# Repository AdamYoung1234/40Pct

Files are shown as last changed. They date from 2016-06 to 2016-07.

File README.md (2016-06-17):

The CW40 (SmallFry 40%) Board
=====

##NOTICE
* This repo is a fork of Regack's 40Pct
* This repo is under CC-BY-SA 3.0 Liscense
* PLEASE MAKE SURE YOU FULLY UNDERSTAND THIS LISCENSE BEFORE YOU USE THE DESIGN.
* 请确保在使用之前完全理解了 CC-BY-SA 3.0协议.

## v0.12
* Change the name to CW40
* Add global backlight
* Add RGB underglow
* Add Alps compatibility

## v0.11
* Change the cystal package to HC49
* Change the mini USB package from SMD to TH

## v0.8-v0.10
* I forget everything that I did, lots of little things
* fixed some unconnected pads (oops)
* cleaned up silkscreens again
* fixed diode pads to fit SOD-123 footprint
* fixed BOM info for components
* rounded PCB edges
* replaced slotted holes with... holes
* added Vcc and Gnd pins to LED expansion
* changed LED expansion pins to 2.54 pitch

## v0.7 - 2013.10.20
* cleaned up silkscreens
* moved 'ROW5' expansion to GPIO7 (still ATMEGA32U4 pin8/PB0)
* added notes
* cleaned up and removed extra libs/mods

## v0.6 - 2013.10.16
* pulled extra pin for ROW5 from ATMEGA pin 8/PB0
* changed drills for holes/slots to work with OSHpark 
* added GPIO4, GPIO5, GPIO6 connectors to ATMEGA pins 26/PD6, 22/PD5, 11/PB3
* ran row and GPIO to 1.27mm headers on right-side of board for interconnect (ribbon cable spacing)

## v0.5 - 2013.09.20
* added back missing slot on right side of board
* added LEDs for optional keys from v0.4
* generated pcb image * not sure why slots don't render properly
* removed bottom-of-board expansion pins

## v0.4 - 2013.09.19
* added optional 1.25+1.0 and 1.0+1.25 for right-shift/fn keys

## v0.3 - 2013.09.18
* based on the GH60 Rev B PCB
* SMT ATMEGA32U4 and other components on back of board
* Expansion ports on bottom and top row
* LEDs on ESC, 'CAPS', and WASD Cluster
* Other LEDs in matrix with expansion points on top row

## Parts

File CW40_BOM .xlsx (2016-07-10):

Reference | Package | Amount
X1 | 16Mhz HC49-S 晶振 | 1
R1 R2 | 0805 22R 电阻 | 2
R3 R4 R5 | 0805 10K 电阻 | 3
C1 C2 | 0805 22pF 电容 | 2
C3 C8 | 0805 1uF 电容 | 2
C4 C5 C6 C7 C9 C10 C11 C12 C13 C14 C15 C16 C17 C18 C19 C20 | 0805 100nF 电容 | 4
LR | 0805 330R 电阻 | 41
S0 | https://item.taobao.com/item.htm?spm=a1z09.2.0.0.rAQpPn&id=24436216995&_u=j1gsagbfc69a | 1
S1-S40 | Cherry MX | 40
D1-D40 | https://item.taobao.com/item.htm?spm=a1z09.2.0.0.rAQpPn&id=25299976699&_u=j1gsagbf3909 | 40
RGB底灯 | WS2812B | 12
Q1 | SI2305 | 1

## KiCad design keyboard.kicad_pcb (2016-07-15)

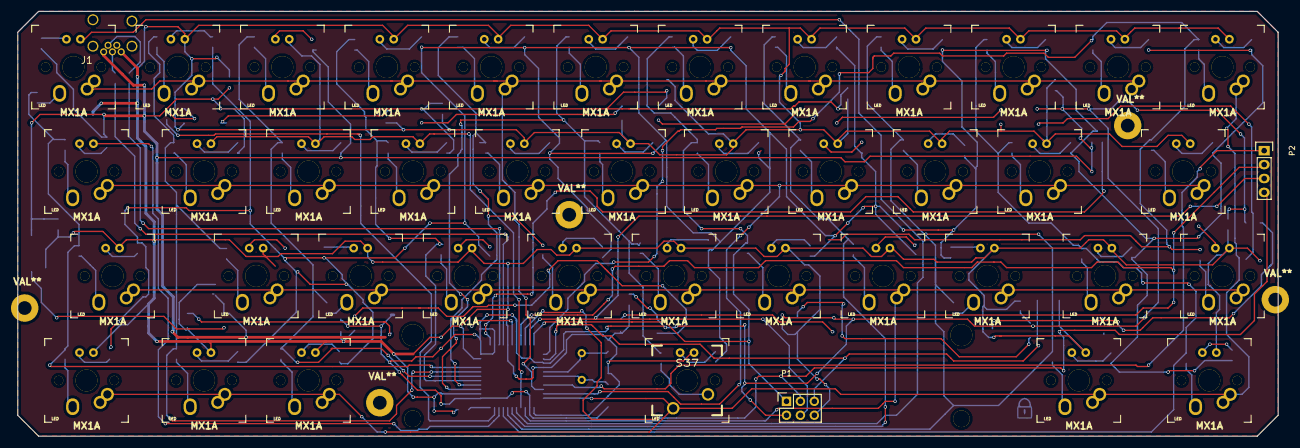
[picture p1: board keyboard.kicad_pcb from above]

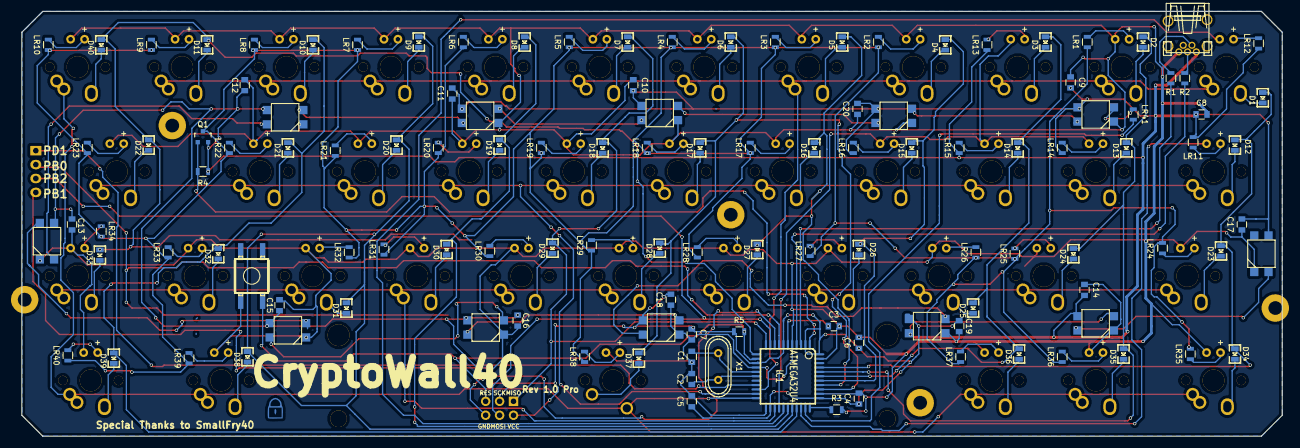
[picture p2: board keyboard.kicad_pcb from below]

Board: 2 copper layers, 229.9 x 77.5 mm, 210 parts (123 on the bottom side), 128 nets.

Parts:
C1, C2: 22pF; C_0805
C3, C8: 1uF; C_0805
C4, C5, C6, C7, C9, C10, C11, C12, C13, C14, C15, C16, C17, C18, C19, C20: 100nF; C_0805
D1, D2, D3, D4, D5, D6, D7, D8, D9, D10, D11, D12, D13, D14, D15, D16, D17, D18, D19, D20, D21, D22, D23, D24, D25, D26, D27, D28, D29, D30, D31, D32, D33, D34, D35, D36, D37, D38, D39, D40: DIODE; SM0805D
IC1: ATMEGA32U4; TQFP44
J1: USBMINI_B05; DX_USB
LED1, LED2, LED3, LED4, LED5, LED6, LED7, LED8, LED9, LED10, LED11, LED12, LED13, LED14, LED15, LED16, LED17, LED18, LED19, LED20, LED21, LED22, LED23, LED24, LED25, LED26, LED27, LED28, LED29, LED30, LED31, LED32, LED33, LED34, LED35, LED36, LED37, LED38, LED39, LED40: LED; MX1A-led
LR1, LR2, LR3, LR4, LR5, LR6, LR7, LR8, LR9, LR10, LR11, LR12, LR13, LR14, LR15, LR16, LR17, LR18, LR19, LR20, LR21, LR22, LR23, LR24, LR25, LR26, LR27, LR28, LR29, LR30, LR31, LR32, LR33, LR34, LR35, LR36, LR37, LR38, LR39, LR40, LR41: 330R; R_0805
MXLED: VAL**; PKRHC
MXLED#2, MXLED#3, MXLED#4, MXLED#5: VAL**; PKRHC
P1: ISP; Socket_Strip_Straight_2x03
P2: GPIO Port; Socket_Strip_Straight_1x04
Q1: MOS_P; SOT-23
R1, R2: 22R; R_0805
R3, R4, R5: 10K; R_0805
RGBLED1, RGBLED2, RGBLED3, RGBLED4, RGBLED5, RGBLED6, RGBLED7, RGBLED8, RGBLED9, RGBLED10, RGBLED11, RGBLED12: WS2812B
S0: DTSM-6
S1, S2, S3, S4, S5, S6, S7, S8, S9, S10, S11, S12, S13, S14, S15, S16, S17, S18, S19, S20, S21, S22, S23, S24, S25, S26, S27, S28, S29, S30, S31, S32, S33, S34, S35, S36, S38, S39, S40: MX1A; MX1ALPS
S37: MX1A; CHERRY_PCB_625H_Rev
X1: CRYSTAL; Crystal_HC49-U_Vertical

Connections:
/GPIO0: IC1.10, P1.4, P2.3
/GPIO1: IC1.9, P1.3, P2.4
/GPIO2: IC1.8, P2.2
/GPIO3: IC1.19, P2.1
/Matrix/Col0: D1.1, D12.1, D23.1, D34.1, IC1.41
/Matrix/Col1: D2.1, D13.1, D24.1, D35.1, IC1.40
/Matrix/Col2: D3.1, D14.1, D25.1, D36.1, IC1.39
/Matrix/Col3: D4.1, D15.1, D26.1, IC1.38
/Matrix/Col4: D5.1, D16.1, D27.1, IC1.37
/Matrix/Col5: D6.1, D17.1, D28.1, D37.1, IC1.36
/Matrix/Col6: D7.1, D18.1, D29.1, IC1.11, P1.1
/Matrix/Col7: D8.1, D19.1, D30.1, IC1.28
/Matrix/Col8: D9.1, D20.1, D31.1, D38.1, IC1.29
/Matrix/Col9: D10.1, D21.1, D32.1, D39.1, IC1.30
/Matrix/Col10: D11.1, D22.1, D33.1, D40.1, IC1.12
/Matrix/Row0: IC1.20, S1.1, S2.1, S3.1, S4.1, S5.1, S6.1, S7.1, S8.1, S9.1, S10.1, S11.1
/Matrix/Row1: IC1.21, S12.1, S13.1, S14.1, S15.1, S16.1, S17.1, S18.1, S19.1, S20.1, S21.1, S22.1
/Matrix/Row2: IC1.25, S23.1, S24.1, S25.1, S26.1, S27.1, S28.1, S29.1, S30.1, S31.1, S32.1, S33.1
/Matrix/Row3: IC1.22, S34.1, S35.1, S36.1, S37.1, S38.1, S39.1, S40.1
/led/Backlight: IC1.1, Q1.G, R4.2
/led/Bottom: IC1.32, LR41.2
/led/CapsLock: IC1.31, LED11.2
/led/ESC: IC1.27, LED12.2
/led/LRow0: LR1.1, LR2.1, LR3.1, LR4.1, LR5.1, LR6.1, LR7.1, LR8.1, LR9.1, LR10.1, LR17.1, LR18.1, LR19.1, LR20.1, LR21.1, LR22.1, LR23.1, LR24.1, LR25.1, LR26.1, LR27.1, LR28.1, LR29.1, LR30.1, LR31.1, LR32.1, LR33.1, LR34.1, LR35.1, LR36.1, LR37.1, LR38.1, LR39.1, LR40.1, Q1.D
/led/WASD: IC1.26, LED13.2, LED14.2, LED15.2, LED16.2
/~Res: IC1.13, P1.5, R5.2, S0.3
GND: C1.2, C2.2, C3.2, C4.2, C5.2, C6.2, C7.2, C8.2, C9.1, C10.1, C11.1, C12.1, C13.1, C14.1, C15.1, C16.1, C17.1, C18.1, C19.1, C20.1, IC1.5, IC1.15, IC1.23, IC1.35, IC1.43, J1.5, LED1.2, LED2.2, LED3.2, LED4.2, LED5.2, LED6.2, LED7.2, LED8.2, LED9.2, LED10.2, LED17.2, LED18.2, LED19.2, LED20.2, LED21.2, LED22.2, LED23.2, LED24.2, LED25.2, LED26.2, LED27.2, LED28.2, LED29.2, LED30.2, LED31.2, LED32.2, LED33.2, LED34.2, LED35.2, LED36.2, LED37.2, LED38.2, LED39.2, LED40.2, P1.6, R3.2, RGBLED1.3, RGBLED2.3, RGBLED3.3, RGBLED4.3, RGBLED5.3, RGBLED6.3, RGBLED7.3, RGBLED8.3, RGBLED9.3, RGBLED10.3, RGBLED11.3, RGBLED12.3, S0.1
unnamed: C1.1, IC1.16, X1.1
unnamed: C2.1, IC1.17, X1.2
unnamed: C3.1, IC1.6
unnamed: D1.2, S1.2
unnamed: D2.2, S2.2
unnamed: D3.2, S3.2
unnamed: D4.2, S4.2
unnamed: D5.2, S5.2
unnamed: D6.2, S6.2
unnamed: D7.2, S7.2
unnamed: D8.2, S8.2
unnamed: D9.2, S9.2
unnamed: D10.2, S10.2
unnamed: D11.2, S11.2
unnamed: D12.2, S12.2
unnamed: D13.2, S13.2
unnamed: D14.2, S14.2
unnamed: D15.2, S15.2
unnamed: D16.2, S16.2
unnamed: D17.2, S17.2
unnamed: D18.2, S18.2
unnamed: D19.2, S19.2
unnamed: D20.2, S20.2
unnamed: D21.2, S21.2
unnamed: D22.2, S22.2
unnamed: D23.2, S23.2
unnamed: D24.2, S24.2
unnamed: D25.2, S25.2
unnamed: D26.2, S26.2
unnamed: D27.2, S27.2
unnamed: D28.2, S28.2
unnamed: D29.2, S29.2
unnamed: D30.2, S30.2
unnamed: D31.2, S31.2
unnamed: D32.2, S32.2
unnamed: D33.2, S33.2
unnamed: D34.2, S34.2
unnamed: D35.2, S35.2
unnamed: D36.2, S36.2
unnamed: D37.2, S37.2
unnamed: D38.2, S38.2
unnamed: D39.2, S39.2
unnamed: D40.2, S40.2
unnamed: IC1.3, R1.1
unnamed: IC1.4, R2.1
unnamed: IC1.33, R3.1
unnamed: J1.2, R1.2
unnamed: J1.3, R2.2
unnamed: LED1.1, LR1.2
unnamed: LED2.1, LR2.2
unnamed: LED3.1, LR3.2
unnamed: LED4.1, LR4.2
unnamed: LED5.1, LR5.2
unnamed: LED6.1, LR6.2
unnamed: LED7.1, LR7.2
unnamed: LED8.1, LR8.2
unnamed: LED9.1, LR9.2
unnamed: LED10.1, LR10.2
unnamed: LED11.1, LR11.2
unnamed: LED12.1, LR12.2
unnamed: LED13.1, LR13.2
unnamed: LED14.1, LR14.2
unnamed: LED15.1, LR15.2
unnamed: LED16.1, LR16.2
unnamed: LED17.1, LR17.2
unnamed: LED18.1, LR18.2
unnamed: LED19.1, LR19.2
unnamed: LED20.1, LR20.2
unnamed: LED21.1, LR21.2
unnamed: LED22.1, LR22.2
unnamed: LED23.1, LR23.2
unnamed: LED24.1, LR24.2
unnamed: LED25.1, LR25.2
unnamed: LED26.1, LR26.2
unnamed: LED27.1, LR27.2
unnamed: LED28.1, LR28.2
unnamed: LED29.1, LR29.2
unnamed: LED30.1, LR30.2
unnamed: LED31.1, LR31.2
unnamed: LED32.1, LR32.2
unnamed: LED33.1, LR33.2
unnamed: LED34.1, LR34.2
unnamed: LED35.1, LR35.2
unnamed: LED36.1, LR36.2
unnamed: LED37.1, LR37.2
unnamed: LED38.1, LR38.2
unnamed: LED39.1, LR39.2
unnamed: LED40.1, LR40.2
unnamed: LR41.1, RGBLED1.4
unnamed: RGBLED1.2, RGBLED2.4
unnamed: RGBLED2.2, RGBLED3.4
unnamed: RGBLED3.2, RGBLED4.4
unnamed: RGBLED4.2, RGBLED5.4
unnamed: RGBLED5.2, RGBLED6.4
unnamed: RGBLED6.2, RGBLED7.4
unnamed: RGBLED7.2, RGBLED8.4
unnamed: RGBLED8.2, RGBLED9.4
unnamed: RGBLED10.2, RGBLED11.4
unnamed: RGBLED9.2, RGBLED10.4
unnamed: RGBLED11.2, RGBLED12.4
VCC: C4.1, C5.1, C6.1, C7.1, C8.1, C9.2, C10.2, C11.2, C12.2, C13.2, C14.2, C15.2, C16.2, C17.2, C18.2, C19.2, C20.2, IC1.2, IC1.7, IC1.14, IC1.24, IC1.34, IC1.44, J1.1, LR11.1, LR12.1, LR13.1, LR14.1, LR15.1, LR16.1, P1.2, Q1.S, R4.1, R5.1, RGBLED1.1, RGBLED2.1, RGBLED3.1, RGBLED4.1, RGBLED5.1, RGBLED6.1, RGBLED7.1, RGBLED8.1, RGBLED9.1, RGBLED10.1, RGBLED11.1, RGBLED12.1

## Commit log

2016-05-14 Change the cyrstal footprint / correct two wrong diode directions
    [keyboard.kicad_pcb, keyboard.sch, leds.sch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]
2016-05-15 Change the footprint of MiniUSB
    [keyboard.kicad_pcb, keyboard.sch]
2016-05-15 Add the latest gerber and change the readme file
    [keyboard-B.Mask.gbs, keyboard-B.Paste.gbp, keyboard-B.SilkS.gbo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]
2016-05-21 Rebuild the project using latest kicad
    Rebuild the project using latest kicad, leaving eschematic and pcb
    unfinished
    [keyboard-B.Mask.gbs, keyboard-B.Paste.gbp, keyboard-B.SilkS.gbo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]
2016-05-21 Final touches on schematic
    [keyboard.sch]
2016-06-02 Minor Changes
    [keyboard.sch, led.sch, matrix.sch]
2016-06-17 ver 0.12
    [keyboard.kicad_pcb, led.sch]
2016-06-18 Fix a mistake in underglow
    [keyboard-B.Adhes.gbr, keyboard-B.Cu.gbr, keyboard-B.Mask.gbr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]
2016-06-18 Update Gerber files
    [keyboard-B.Adhes.gbr, keyboard-B.Cu.gbr, keyboard-B.Mask.gbr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]
2016-06-23 Slight changes on edge
    Gerber files updated also.
    [keyboard-B.Adhes.gbr, keyboard-B.Cu.gbr, keyboard-B.Mask.gbr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]
2016-07-01 a lot of changes
    [keyboard.kicad_pcb, keyboard.sch, led.sch]
2016-07-02 minor changes & update gerber files
    [keyboard-B.Adhes.gbr, keyboard-B.Cu.gbr, keyboard-B.Mask.gbr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]
2016-07-02 Add BOM
    [CW40_BOM .xlsx]
2016-07-03 add gerber.rar
2016-07-09 final version
    [keyboard-B.Adhes.gbr, keyboard-B.Cu.gbr, keyboard-B.Mask.gbr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]
2016-07-10 update bom
    [CW40_BOM .xlsx, keyboard.kicad_pcb]
2016-07-11 Update Silkscreen
    [keyboard-B.Adhes.gbr, keyboard-B.Cu.gbr, keyboard-B.Mask.gbr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]
2016-07-13 Rev 1.0 Pro
    [keyboard-B.Adhes.gbr, keyboard-B.Cu.gbr, keyboard-B.Mask.gbr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]
